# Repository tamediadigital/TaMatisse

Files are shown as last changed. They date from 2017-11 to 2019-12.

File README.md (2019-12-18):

#  TaMatisse

TaMatisse aka the Tamedia Robo-Painter is a small Arduino painting robot that has been developed for the Zukunftstag 2017 at Tamedia.
The Zukunftstag is a special day in Switzerland where 10-12 year old kids join their parents at work to get an impression of what their working day looks like.

The name of this project is inspired by [Henri Matisse](https://en.wikipedia.org/wiki/Henri_Matisse) - so our bots have somebody to look up to.

For this project, we designed the robots from scratch, 3D-printed the chassis and the wheels and powered them with an Arduino board and motors. We went through a number of iterations starting from [a very rudimental version](https://drive.google.com/open?id=1XHYLBMp3aTwPATsHcA2afbOtKss3Xp65) which gave some [first promising results](https://drive.google.com/open?id=1dIKPrNfxLv_RLu-L1qv47xOSfsh7SLXa).

That wasn't enough of course!

So we continued improving the design until we [finalized the chassis](https://drive.google.com/open?id=1kGrtJrTfS0Q7jIdkaZlRN-G9279_aEaJ) and printed the various components as you can see [here](https://drive.google.com/open?id=0BwoCo__hMSJ6NEFHOGhoUWRwV2ZKOFBrdkJ0M2RfVTFDbWM0) and [here](https://drive.google.com/open?id=0BwoCo__hMSJ6SFZKb2V2S29RN1BaV2FIQ3VYTy1DRmxQTV9F). Overall, it was [a lot of work](https://drive.google.com/open?id=0BwoCo__hMSJ6SUVaUnR0QjBXb0xCNW9nZUJrU2hhVGdiVzZz) but we are very proud of [the functioning protoype](https://drive.google.com/open?id=0BwoCo__hMSJ6RV90MGFNMHpCRGxlZ05hVXpPWWNkQTBjVlBn).

We were particularly impressed by the [precision](https://drive.google.com/open?id=0BwoCo__hMSJ6eWh6UDM4QzQtRDBOaHNTTVJySDduU3U4T1pR) in the first test run and so we started getting creative, teaching TaMatisse a lot of [new patterns](https://drive.google.com/open?id=1D4qrHpUrIhioHyt2ebI3qsHQg5HWzTjb) to draw more and more complicated pictures.

We've created a small library that holds some geometrical primitives (straight line, curve,....) that can be used to draw larger, more complex drawings.

We want to have the kids figure out the right sequence and parameters for these primitives in order to produce shapes as simple as squares and circles up to more complex ones such as stars or flowers.

The extra challenge in this version of TaMatisse is that the marker never leaves the paper so you really need to figure out the optimal path to obtain a clean shape!

# Technical Specs

If you're interested to build TaMatisse and try it out for yourself, here's what you need:

* Access to a 3D printer to print the chassis and the wheels
* An Arduino Nano (sold in many online stores, https://store.arduino.cc/arduino-nano)
* 2 x 28BYJ-48 5V Stepper motors with 2 x Uln2003 driver board (buy the board and the board in one package)
* On/Off Switch (we used Universal Car Styling 16A 12V LED Dot Light Car Boat Round Rocker ON/OFF SPST Switch https://www.aliexpress.com/item/32829587850.html?spm=a2g0s.9042311.0.0.649d4c4dOiJ8gw)
* Battery-holder (4 x AA, next to each other. We used https://www.aliexpress.com/item/32818907820.html?spm=a2g0s.9042311.0.0.649d4c4dOiJ8gw)
* Some Dupont Cable 20cm 2.54mm Female-Female - best with color codes.
* Soldering iron to combine 5V and ground pins of the two stepper motor boards, the Arduino and the battery pack / power switch. 
* 2 x Rubber bands for around the wheels
* 4 x AA Batteries
* Whiteboard markers (size is optimized for the lyreco brand)
* PlatformIO-IDE - an opensource IoT platform for compiling the git-repo and upload the code to the bot.
* For beginners, please refer to [this visual guide](HOWTO.md).

Happy painting!

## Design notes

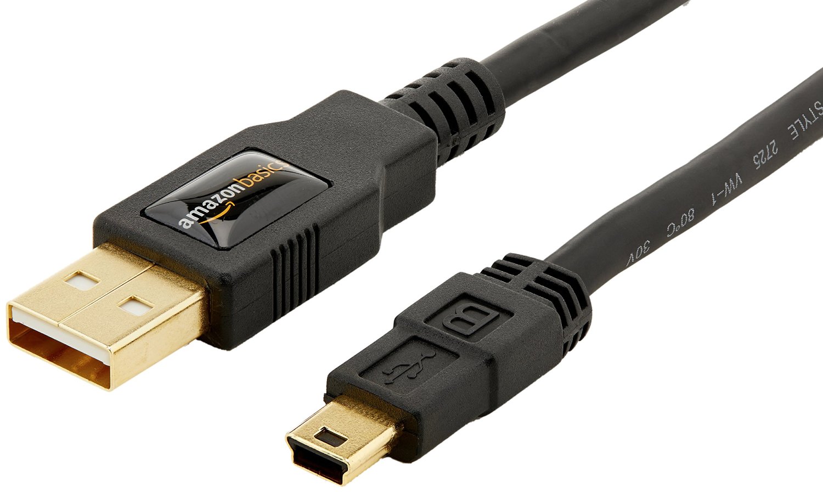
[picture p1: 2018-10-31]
doc/images/usb-a-to-usb-mini-b.jpg

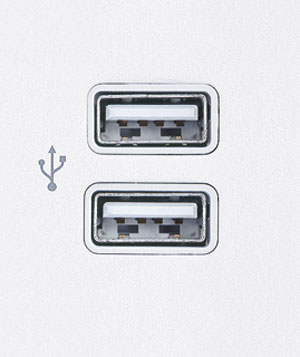
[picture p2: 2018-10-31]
doc/images/usb-a-port.jpg

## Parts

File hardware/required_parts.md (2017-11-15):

# Required Hardware for build a TaMatisse robot

## Electroincs

* 2 x 28BYJ-48 5V 4 Phase DC Gear Stepper Motor + ULN2003 Driver Board
* 1 x Arduino Nano
* 1 x 4 x AA Battery Case with cable (flat, so the batteries are next to each other)
* 1 x Power Switch 
* 14 x Dupont cable female-female, ideally 20cm

## Mechanical

* 4 x M3 screws 16mm, panhead
* 7 or 11 M3 screws 6mm, panhead (for attaching stepper motor controller and Arduino Nano and wheels)
* 2 x M3 screws 6mm, countersunk for attaching the battery case
* 2 x rubberbands (for creating friction on the wheels)
* 1 thick pen (18mm diameter) for painting

## Chassis

* 1 x 3D printed chassis
* 2 x 3D printed wheels
* 1 x 3D printed fin

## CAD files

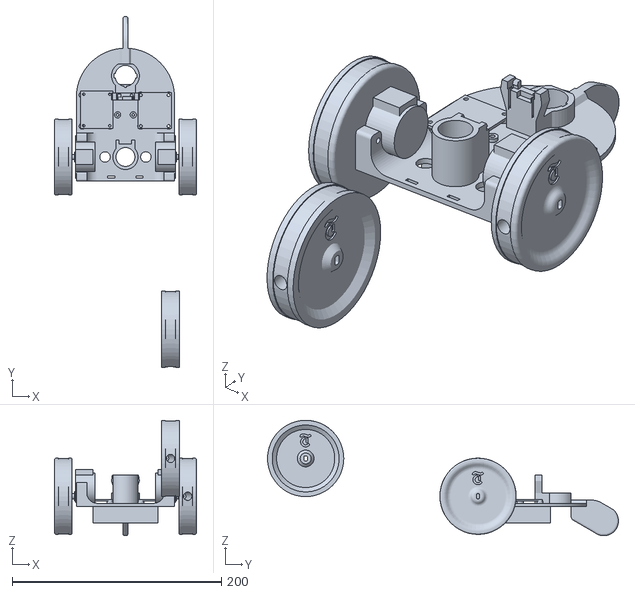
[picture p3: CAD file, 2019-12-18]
hardware/3D-model/STL/TaMattisse-fin.stl
135.9 x 335.8 x 110.4

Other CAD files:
hardware/3D-model/STL/TaMattisse-wheel.stl
hardware/3D-model/PenTop.skp
hardware/3D-model/TaMattisse-chassis.skp

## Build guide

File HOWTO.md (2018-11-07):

# How To TaMatisse

## Hardware and software requirements
- A laptop with a [USB-A port](doc/images/usb-a-port.jpg)
- [USB-A to USB mini B](doc/images/usb-a-to-usb-mini-b.jpg) cable
- A copy of this repository
- [VSCode](https://code.visualstudio.com/) or [Atom](https://atom.io/) text editors, with the [PlatformIO plugin](https://platformio.org/platformio-ide) installed
- A functioning TaMatisse bot.

## Step by step guide to building and uploading the software

__1. Start your editor (VSCode/Atom) and launch the PlatformIO pluign__
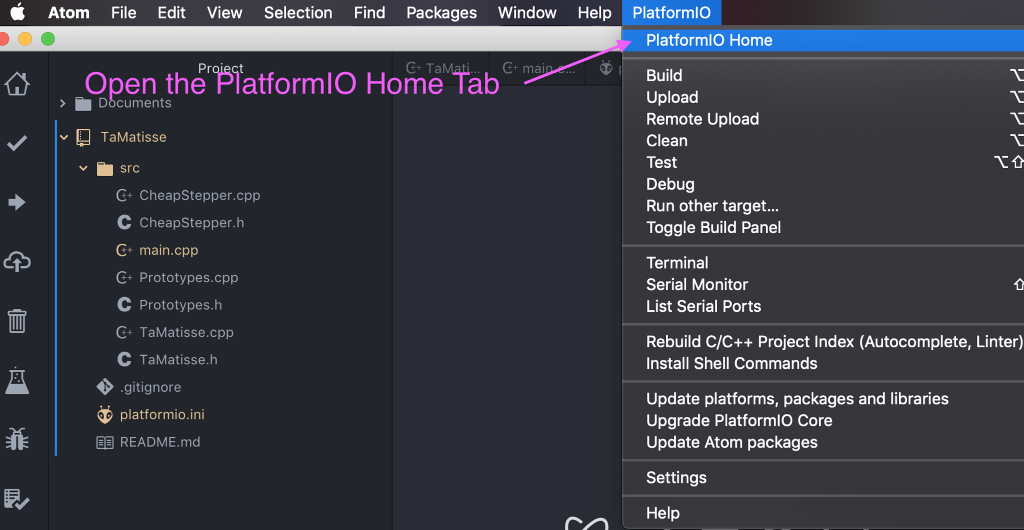
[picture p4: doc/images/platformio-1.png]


__2. Open your project in PlatformIO__ 
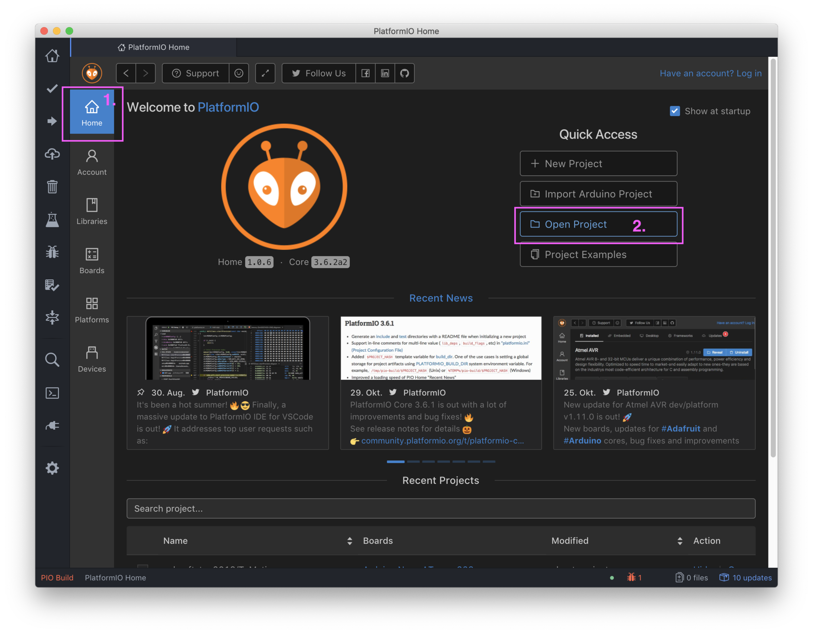
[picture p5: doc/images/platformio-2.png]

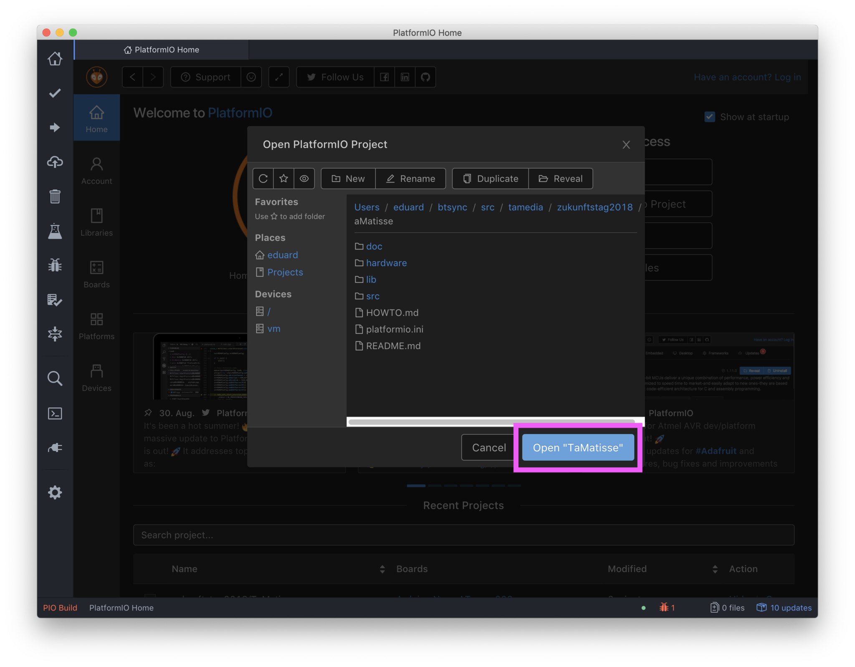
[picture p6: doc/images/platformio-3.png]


__3. Install the "Atmel AVR" platform__ 
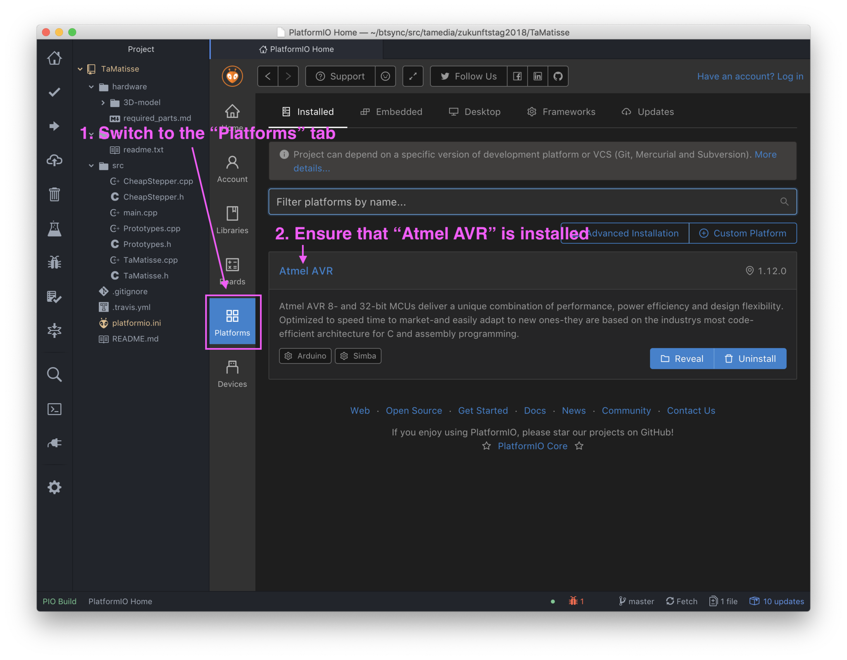
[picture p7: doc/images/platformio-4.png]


__4. Build the project__
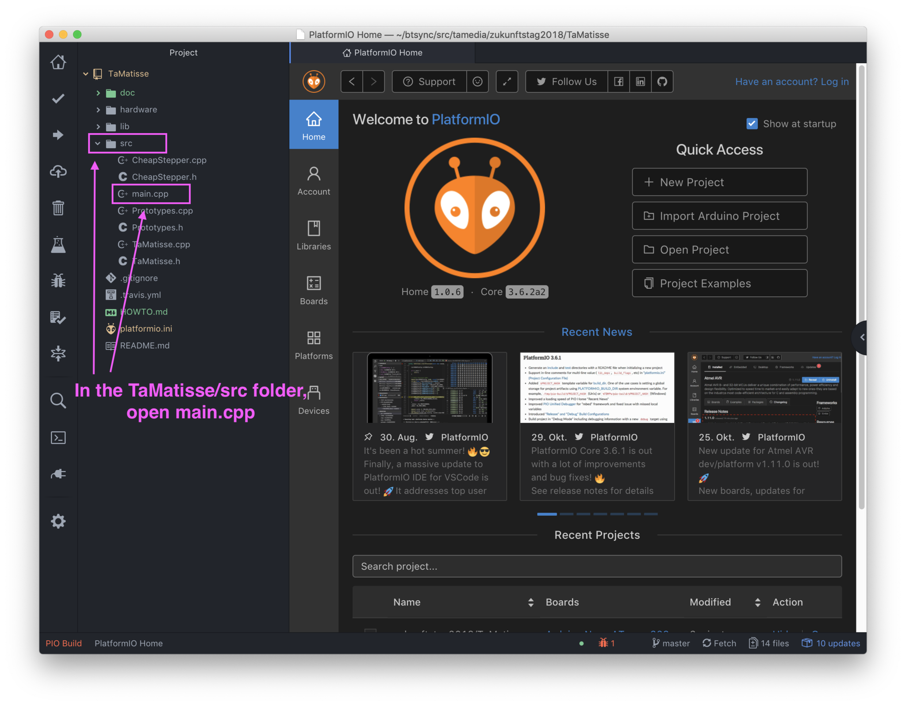
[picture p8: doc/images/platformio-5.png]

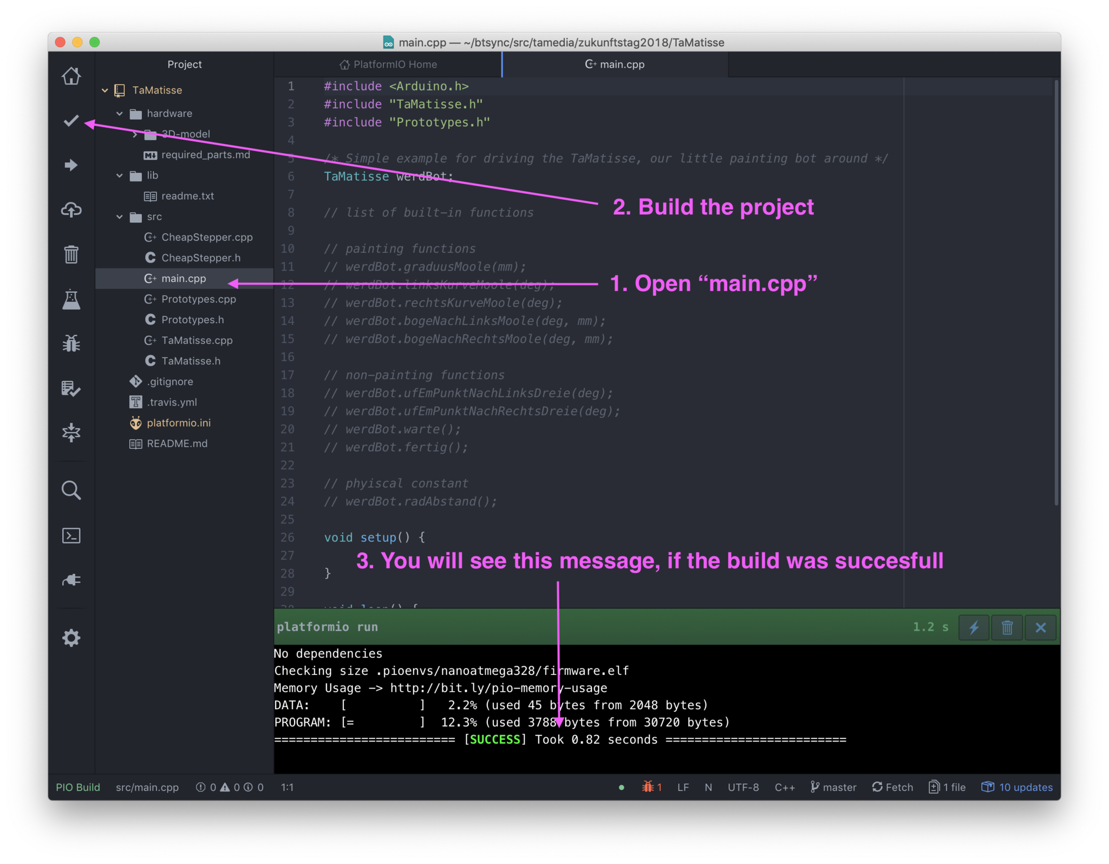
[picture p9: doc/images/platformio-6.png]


__5. Upload to the Arduino (Atmel AVR)__
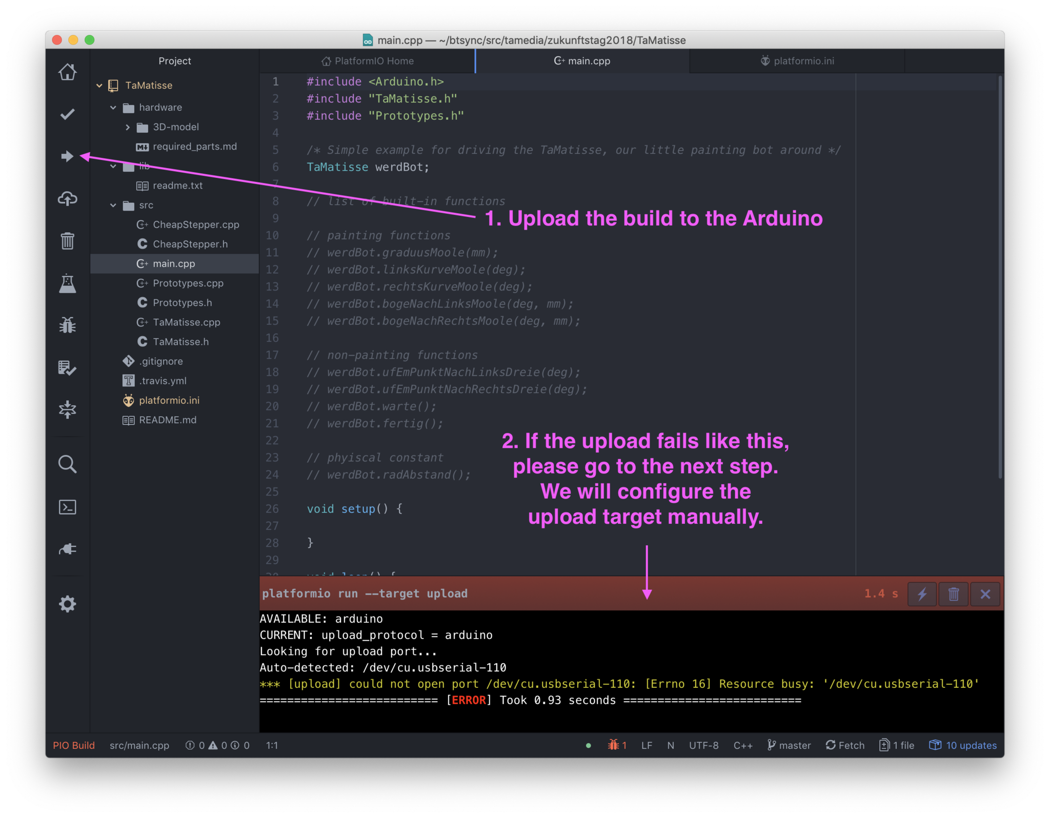
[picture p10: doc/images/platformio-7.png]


__5.1. If uploading doesn't work, change the upload target port__

PlatformIO automatically tries to detect which USB serial port to upload to. Sometimes this doesn't work, therefore we have to specify the port in the platformio.ini file. If you're using OSX it may also be your laptop is missing the right drivers for the CH34x USB to Serial chip in which case you won't see the the 'usbserial' device listed at all - see below.

Find the correct port:
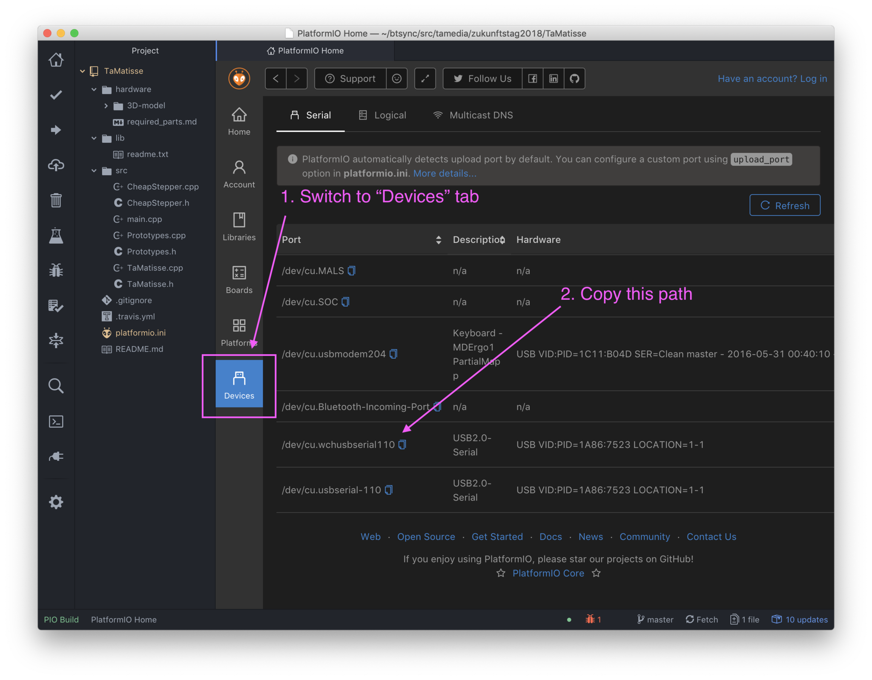
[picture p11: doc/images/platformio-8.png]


Set new port in platformio.ini:
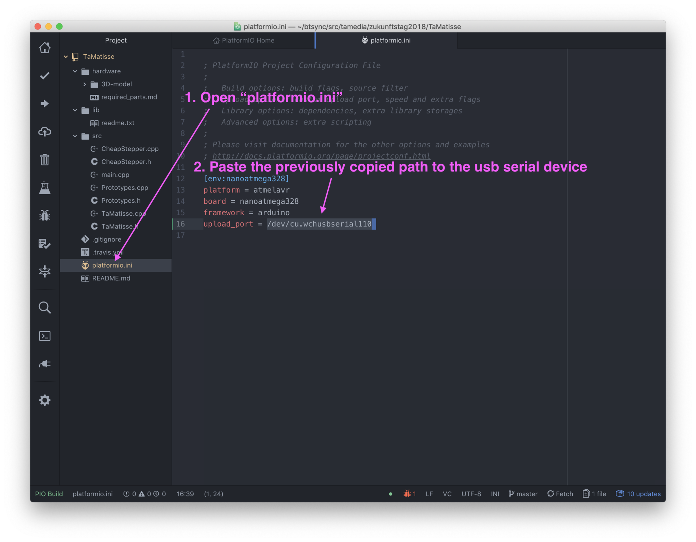
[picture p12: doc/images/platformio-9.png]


__5.2. Install the CH34x USB to Serial Drivers:__

Taken from [this guide](https://github.com/adrianmihalko/ch340g-ch34g-ch34x-mac-os-x-driver)

```
brew tap mengbo/ch340g-ch34g-ch34x-mac-os-x-driver https://github.com/mengbo/ch340g-ch34g-ch34x-mac-os-x-driver
brew cask install wch-ch34x-usb-serial-driver
```

After that you'll need to restart and go back to point 5 above.

__5.3. Successful upload:__
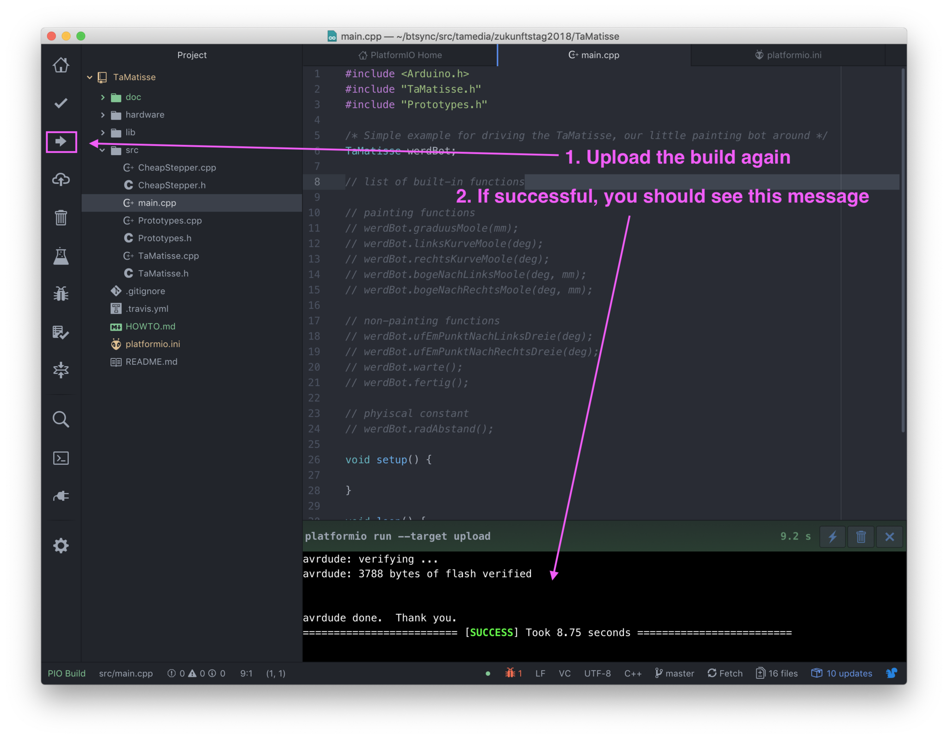
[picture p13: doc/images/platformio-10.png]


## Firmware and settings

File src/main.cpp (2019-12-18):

#include <Arduino.h>
#include "TaMatisse.h"
#include "Prototypes.h"

TaMatisse werdBot;

// list of built-in functions

// painting functions
// werdBot.graduusMoole(mm);
// werdBot.linksKurveMoole(deg);
// werdBot.rechtsKurveMoole(deg);
// werdBot.bogeNachLinksMoole(deg, mm);
// werdBot.bogeNachRechtsMoole(deg, mm);

// non-painting functions
// werdBot.ufEmPunktNachLinksDreie(deg);
// werdBot.ufEmPunktNachRechtsDreie(deg);
// werdBot.warte();
// werdBot.fertig();

// phyiscal constant
// werdBot.radAbstand();

void setup() {

}

void loop() {
  werdBot.graduusMoole(40);
  werdBot.graduusMoole(-40);

}

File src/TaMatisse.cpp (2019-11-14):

/*  TaMatisse.cpp -
  v0.2 es 20191113 Rewrote movement function to use AccelStepper
	v0.1 tg 20171106 rudimentary setup with the first 3 primitives

  Simple library to draw some primitives with TaMatisse, the little bot
  for the Zukunftstag 2017 at Tamedia. It relieas on the CheapStepper
  Library https://www.airspayce.com/mikem/arduino/AccelStepper/ by Mike McCauley
*/

#include <Arduino.h>
#include "TaMatisse.h"

TaMatisse::~TaMatisse()
{
  delete motor_L;
  delete motor_R;
}

TaMatisse::TaMatisse()
{
  int motorRPin1 = 8;  // IN1 on the ULN2003 driver
  int motorRPin2 = 9;  // IN2 on the ULN2003 driver
  int motorRPin3 = 10; // IN3 on the ULN2003 driver
  int motorRPin4 = 11; // IN4 on the ULN2003 driver

  int motorLPin1 = 3; // IN1 on the ULN2003 driver
  int motorLPin2 = 4; // IN2 on the ULN2003 driver
  int motorLPin3 = 5; // IN3 on the ULN2003 driver
  int motorLPin4 = 6; // IN4 on the ULN2003 driver

  int motorType = 8; // Define the AccelStepper interface type; 4 wire motor in half step mode
  int acceleration_R = 200;
  int acceleration_L = 200;

  speed_R = 400;
  speed_L = 400;

  // Initialize with pin sequence PIN1-PIN3-PIN2-PIN4 for using the AccelStepper library with 28BYJ-48 stepper motor:
  motor_R = new AccelStepper(motorType, motorRPin1, motorRPin3, motorRPin2, motorRPin4);
  motor_L = new AccelStepper(motorType, motorLPin1, motorLPin3, motorLPin2, motorLPin4);

  // Set the maximum steps per second:
  motor_R->setMaxSpeed(1000);
  motor_L->setMaxSpeed(1000);

  // Set the maximum acceleration in steps per second^2:
  motor_R->setAcceleration(acceleration_R);
  motor_L->setAcceleration(acceleration_L);
}

void TaMatisse::graduusMoole(float mm)
{
  motor_L->setCurrentPosition(0);
  motor_R->setCurrentPosition(0);

  int steps = calculateSteps(mm);

  motor_L->moveTo(steps);
  motor_R->moveTo(steps * -1);

  while (motor_L->distanceToGo() != 0 && motor_R->distanceToGo() != 0)
  {
    motor_L->run();
    motor_R->run();
  }

  delay(WAIT_AFTER_PRIMITIVE);
}

void TaMatisse::rechtsKurveMoole(float degree)
{
  motor_R->setCurrentPosition(0);
  motor_L->setCurrentPosition(0);

  int steps = calculateSteps(WHEEL_DISTANCE * PI * 2 / (360.0 / degree));

  motor_L->moveTo(steps);

  while (motor_L->distanceToGo() != 0)
  {
    motor_L->run();
  }

  delay(WAIT_AFTER_PRIMITIVE);
}

void TaMatisse::linksKurveMoole(float degree)
{
  motor_R->setCurrentPosition(0);
  motor_L->setCurrentPosition(0);

  //int steps = calculateSteps(((WHEEL_DISTANCE / 2) * PI * 2) * (degree / 360.0));
  int steps = calculateSteps(WHEEL_DISTANCE * PI * 2 / (360.0 / degree));

  motor_R->moveTo(steps * -1);

  while (motor_R->distanceToGo() != 0)
  {
    motor_R->run();
  }

  delay(WAIT_AFTER_PRIMITIVE);
}

void TaMatisse::ufEmPunktNachRechtsDreie(float degree)
{
  motor_L->setCurrentPosition(0);
  motor_R->setCurrentPosition(0);

  int steps = calculateSteps(((WHEEL_DISTANCE / 2) * PI * 2) * (degree / 360.0));
  //steps = 860;
  motor_R->moveTo(steps);
  motor_L->moveTo(steps);

  while (motor_L->distanceToGo() != 0 && motor_R->distanceToGo() != 0)
  {
    motor_L->run();
    motor_R->run();
  }

  delay(WAIT_AFTER_PRIMITIVE);
}

void TaMatisse::ufEmPunktNachLinksDreie(float degree)
{
  motor_L->setCurrentPosition(0);
  motor_R->setCurrentPosition(0);

  int steps = calculateSteps(((WHEEL_DISTANCE / 2) * PI * 2) * (degree / 360.0));

  motor_R->moveTo(steps * -1);
  motor_L->moveTo(steps * -1);

  while (motor_L->distanceToGo() != 0 && motor_R->distanceToGo() != 0)
  {
    motor_L->run();
    motor_R->run();
  }

  delay(WAIT_AFTER_PRIMITIVE);
}

void TaMatisse::bogeNachRechtsMoole(float degree, float radius)
{
  int stepsLeft = calculateSteps((degree / 360) * (2 * PI * (radius + (WHEEL_DISTANCE / 2))));
  int stepsRight = calculateSteps((degree / 360) * (2 * PI * (max(0, radius - (WHEEL_DISTANCE / 2)))));

  float stepsDifference = abs(stepsLeft - stepsRight);
  float stepsRatio = stepsDifference / stepsLeft;
  float accelRight = speed_R * (1 - stepsRatio);

  motor_L->setCurrentPosition(0);
  motor_R->setCurrentPosition(0);

  // We have to switch from acceleration mode to constant speed setCurrentPosition has the side effect of setting speed to 0
  motor_R->setSpeed(accelRight * -1);
  motor_L->setSpeed(speed_L);

  while (motor_L->currentPosition() != stepsLeft)
  {
    motor_L->runSpeed();

    if (motor_R->currentPosition() != stepsRight)
    {
      motor_R->runSpeed();
    }
  }
  delay(WAIT_AFTER_PRIMITIVE);
}

void TaMatisse::bogeNachLinksMoole(float degree, float radius)
{
  int stepsLeft = calculateSteps((degree / 360) * (2 * PI * (max(0, radius - (WHEEL_DISTANCE / 2)))));
  int stepsRight = calculateSteps((degree / 360) * (2 * PI * (radius + (WHEEL_DISTANCE / 2))));

  float stepsDifference = abs(stepsLeft - stepsRight);
  float stepsRatio = stepsDifference / stepsRight;
  float accelLeft = speed_L * (1 - stepsRatio);

  motor_L->setCurrentPosition(0);
  motor_R->setCurrentPosition(0);

  // We have to switch from acceleration mode to constant speed setCurrentPosition has the side effect of setting speed to 0
  motor_R->setSpeed(speed_R * -1);
  motor_L->setSpeed(accelLeft);

  while (motor_R->currentPosition() != stepsRight * -1)
  {
    motor_R->runSpeed();

    if (motor_L->currentPosition() != accelLeft)
    {
      motor_L->runSpeed();
    }
  }
  delay(WAIT_AFTER_PRIMITIVE);
}

void TaMatisse::warte(int seconds)
{
  for (int i = 0; i < seconds; i++)
    delay(1000);
}

void TaMatisse::fertig(void)
{
  for (;;)
    delay(3600UL * 1000);
}

float TaMatisse::radAbstand(void)
{
  return WHEEL_DISTANCE;
}

/////////////
// PRIVATE //
/////////////

int TaMatisse::calculateSteps(float mm)
{
  int steps = roundf(mm / ((DIAMETER * PI) / STEPS_PER_ROUND));
  return steps;
}

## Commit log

2017-11-07 Fixed the HelloWorld, whells were turning patrially in the wrong direction
    [TaMatisse.cpp]
2017-11-07 Calculate the radius from the tip of the pen and not from the left or right wheel.
2017-11-07 Make the bogeNachXMoole work with a radius smaller than WHEEL_DISTANCE / 2
2017-11-07 new wheel distance for improved stability of the chassis
2017-11-08 Add warte(int seconds) und fertig(void) two functions to help drawing complex stuff by waiting a little or a lot :)
2017-11-08 Add a schnaegg (spiral) and the tutti-t to the main.cpp, rearange it a bit so we don't need prototypes.
2017-11-08 Add a possible calibration function since the wheel diameter and distance are rather important numbers to have right.
2017-11-09 Move the functions from main.cpp to Prototypes.cpp. We can add as many functions in there without disturbing the playground for the kids too much.
    [main.cpp]
2017-11-09 Fixed (?) issue with Prototypes header
2017-11-09 Make the chriesi laessig and fix some prototypes.
2017-11-09 Add a getter to get the wheel distance
2017-11-09 Add a function to print regular n-sided shapes
2017-11-09 Use 137.0 for the wheel distance. This is good enough for most bots.
2017-11-09 Much simpler calibration function. Works quite well.
2017-11-09 Switch the hertz function to use the radAbstand function.
2017-11-15 adding first version of required materials
2017-11-15 adding Sketchup files
    [PenTop.skp, TaMattisse-chassis.skp]
2017-11-15 adding STL files
    [TaMattisse-chassis.stl, TaMattisse-fin.stl, TaMattisse-wheel.stl]
2018-11-06 Add note on install the CH34x drivers
2019-11-14 Rewrote movement functions to use AccelStepper
    We were having issues with stepper control, since we updated the hardware in 2018.
    The rewrite solved most things.
    [TaMatisse.cpp, main.cpp]
2019-11-19 + updated README to include the details of the electronics used + updated the 3D-files to include the latest updates in the chassis
    [TaMattisse-chassis.skp, TaMattisse-chassis.stl, TaMattisse-fin.stl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]
2019-12-18 Re-add the API list, removed it by mistake
    [main.cpp]
